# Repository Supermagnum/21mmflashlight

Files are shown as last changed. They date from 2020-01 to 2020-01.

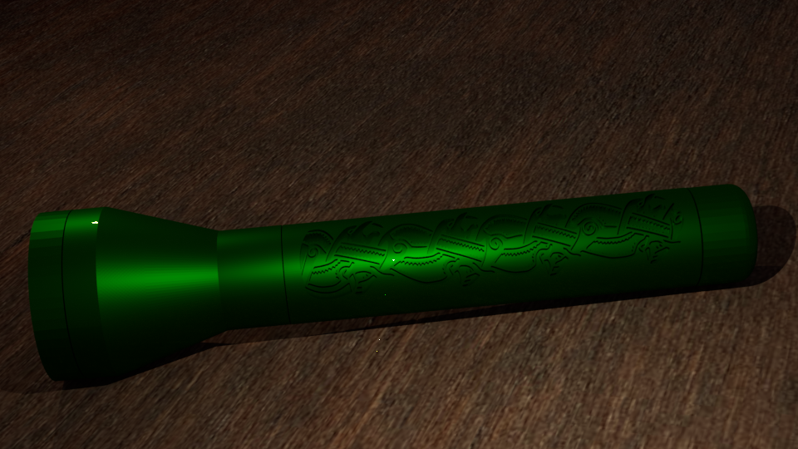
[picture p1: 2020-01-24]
pictures/grønn.png

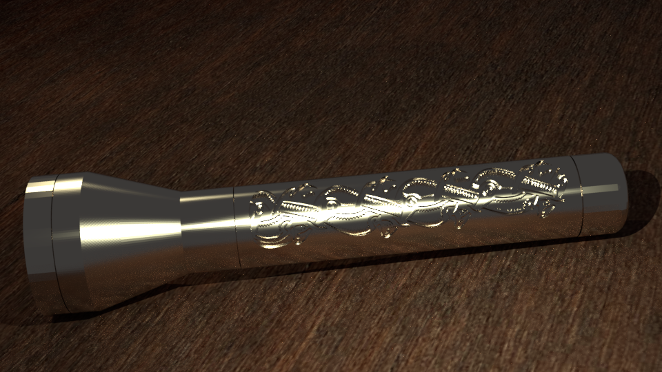
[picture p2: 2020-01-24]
pictures/nikkel.png

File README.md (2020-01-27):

# 21mmflashlight
This is a repository for a flashlight.
It can be made using a normal lathe and a drill press or a milling machine. A multi axis CNC is required for the fancy engraving.

You will need a round stock that has 60mm diameter and suitable length, material 6061 aluminium alloy to make this flashlight. You will need to thread the parts as you see fit, and add knurling.

If Anodizing is added as a surface treatment, the threads must be left bare, as the chassis is DC negative and electric connections must be preserved.

It takes two 21700 lithium ion batteries ( 21 mm diameter and 70mm length), I think that protected ones with a button top should fit. 

It is also smart to use a good quality thermal paste on the backside of the LED pcb. Something like NT-H1 from Noctua is good. Ordinary electric conductive copper paste can perhaps be used on the threads on the part that holds the two PCB's to improve the thermal conductivity.

LED driver:
http://www.international.mtnelectronics.com/index.php?route=product/product&path=67_117&product_id=888
Alternatively ( the pocket for the LED driver will need to be modified to the correct diameter and depth for this one):
https://asflashlights.com/-diy-parts/75-10-amp-capable-17mm-led-driver.html

Note on the LED driver: I dont know if it has any protection agains reverse polarity, but its easy to add that. Just use this PCB:
https://oshpark.com/shared_projects/QlLKpYoS

LED ( You will need the 6V 20mm version ):
http://www.international.mtnelectronics.com/index.php?route=product/product&path=60_114&product_id=867

OFF/ON switch:
https://www.digikey.com/product-detail/en/te-connectivity-alcoswitch-switches/AV1911000Q04/450-2229-ND/6043720
The part number is: AV1911000Q04 
One leg of the switch must be connected to the endcap,as the DC negative connection is switched. The switch may require a small spring and a plastic spacer so the other leg is in contact with the batterys negative therminal. The spacer may be necessary to avoid shorts with the switches other unused pins.It's also some soldering involved, the legs on the switch,and the wires from the driver PCB is the ones that needs soldering. That is four points total.

Lens:
http://www.international.mtnelectronics.com/index.php?route=product/product&product_id=70

Reflector:
https://www.mtnelectronics.com/index.php?route=product/product&path=68_101&product_id=495

All the IGES files,STL files and SVG blueprints are in their folders.
The viking-holder file has a engraving with graphics from a sword hilt found at Alm in Stange, Norway. It's from around year 800. That is only avaible as a STL file, because the IGES file is too large for Github. Its here:
https://github.com/Supermagnum/21mmflashlight/blob/master/stl/viking-holder.stl

The Freecad file with all the parts is:
https://github.com/Supermagnum/21mmflashlight/blob/master/21mm.FCStd

FreeCAD can be downloaded free at:
https://www.freecadweb.org/

Its free and multi platform!

Remember to read the license for these files, it is here:
https://github.com/Supermagnum/21mmflashlight/blob/master/LICENSE

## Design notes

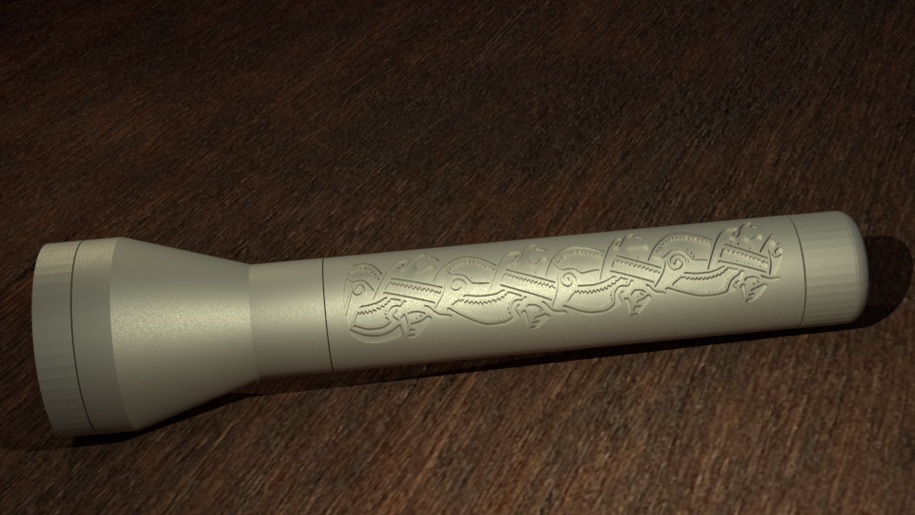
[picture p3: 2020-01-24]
pictures/graa.png

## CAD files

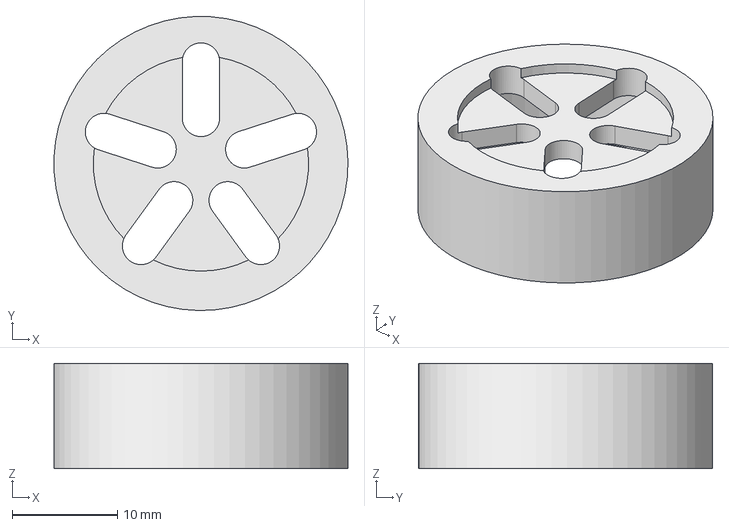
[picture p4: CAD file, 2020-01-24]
21mm.FCStd
28.0 x 28.0 x 10.0 mm

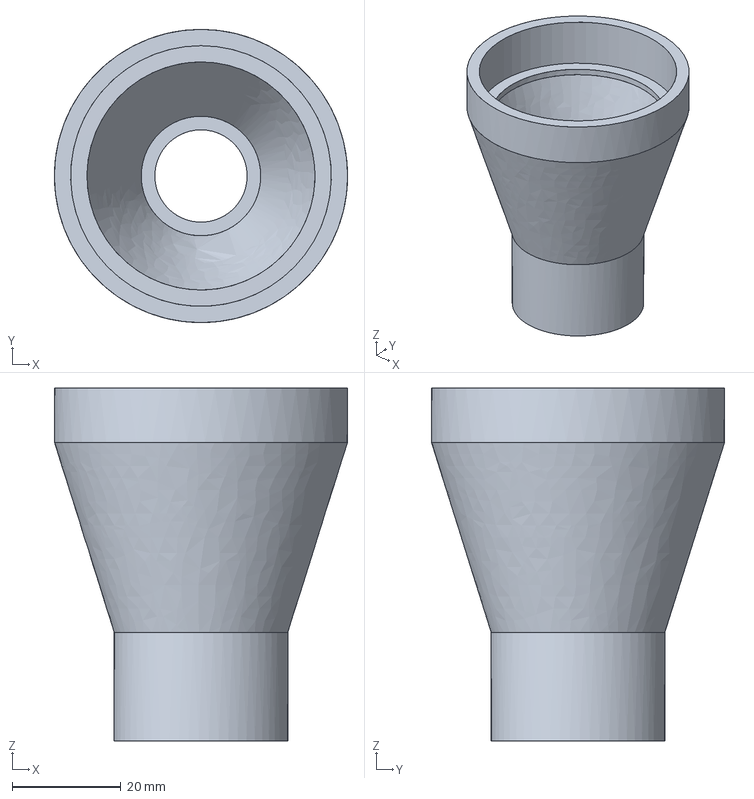
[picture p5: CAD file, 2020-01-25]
IGES/flashlight-head.iges
54.0 x 54.0 x 65.0 mm

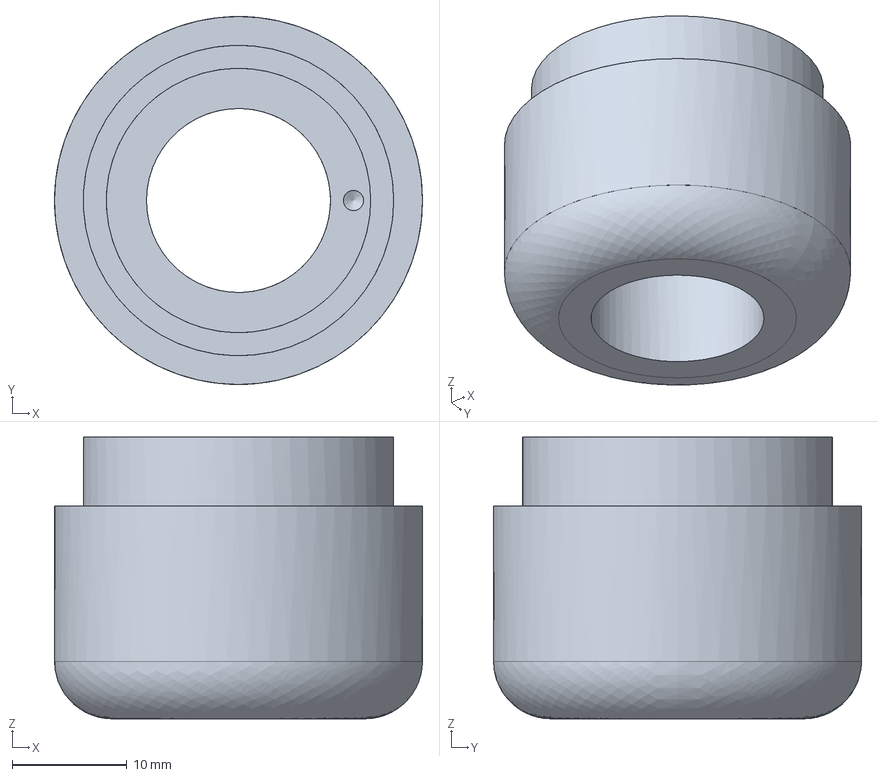
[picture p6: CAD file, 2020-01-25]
IGES/endcap.iges
32.0 x 32.0 x 24.5 mm

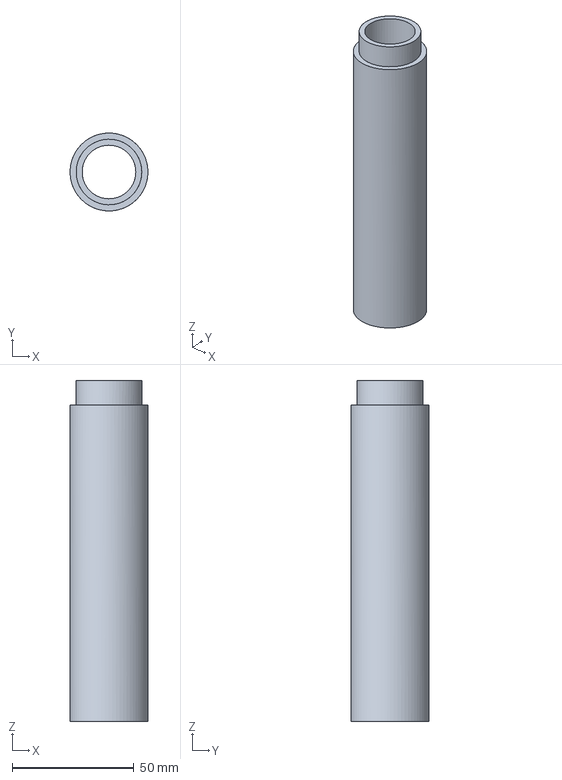
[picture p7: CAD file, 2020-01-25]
IGES/battery-holder.iges
32.0 x 32.0 x 140.0 mm

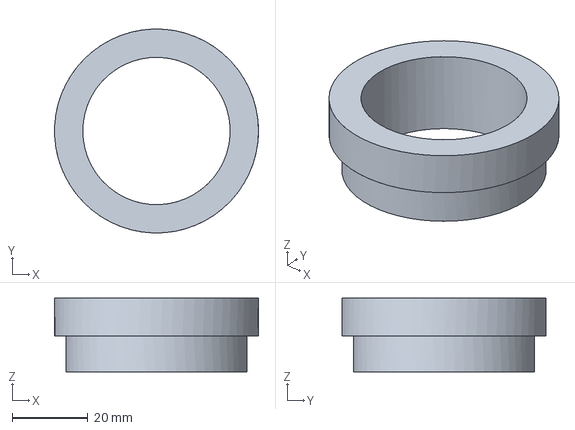
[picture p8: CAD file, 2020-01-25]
IGES/lensholder.iges
54.0 x 54.0 x 19.5 mm

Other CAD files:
stl/head.stl
IGES/led-holder.iges
stl/endcap.stl
stl/led-holder.stl
stl/lensholder.stl

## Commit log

2020-01-24 Add files via upload
    Added missing part
    [led-holder.stl]
2020-01-25 RE upload
    [battery-holder.iges, endcap.iges, flashlight-head.iges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]
